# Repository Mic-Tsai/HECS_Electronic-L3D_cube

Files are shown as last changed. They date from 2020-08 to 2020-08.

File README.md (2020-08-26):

## L3D_cube_4x4x4



Use the microphone to design an interactive experience.
You will figure out the LEDs will start dancing with the music!

```
Arduino tool kit, and require following breakout board:
- MCU: Arduino 
- Display: WS2812B-5050
- Power source: Li-Po Battery
```

##

### **About Mic**

Director of HECS, design light painting product which contains hardware layout and software programming.

- [Resume](https://drive.google.com/file/d/1NEWwNo3X4ogJMNzp6jpFyT0a6GPGhs7Q/view)

## 

### **About HECS**

If you interesting how it works please refer for detail:

- [HECS Electronics](https://drive.google.com/file/d/1tgr780FQ_Ib0JO3FdQn_M6LVbDeVmUmG/view?usp=sharing)

## 

If you want to buy this board and are in Taiwan, please visit my shop: 

Will OPEN SOON:
* [HECS SHOP](https://www.)
* Contact me via mail (xbcke12345@gmail.com)
* If this project helping. Please generously support =)

   

##
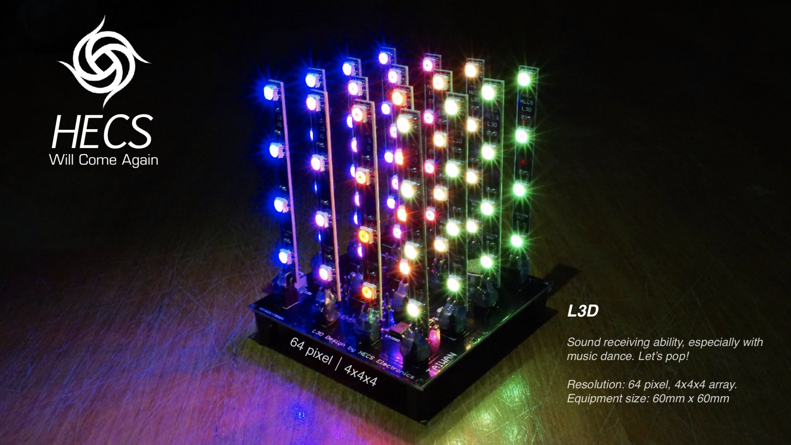
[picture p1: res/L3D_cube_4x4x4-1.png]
*L3D_cube_4x4x4*

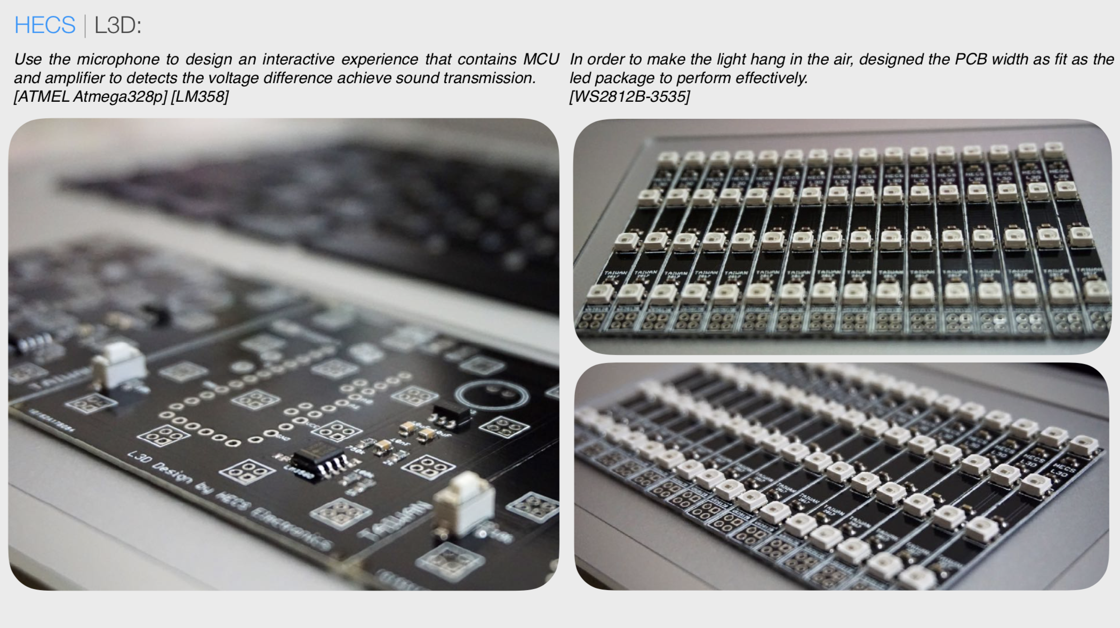
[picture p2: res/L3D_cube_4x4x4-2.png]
*L3D_cube_4x4x4*

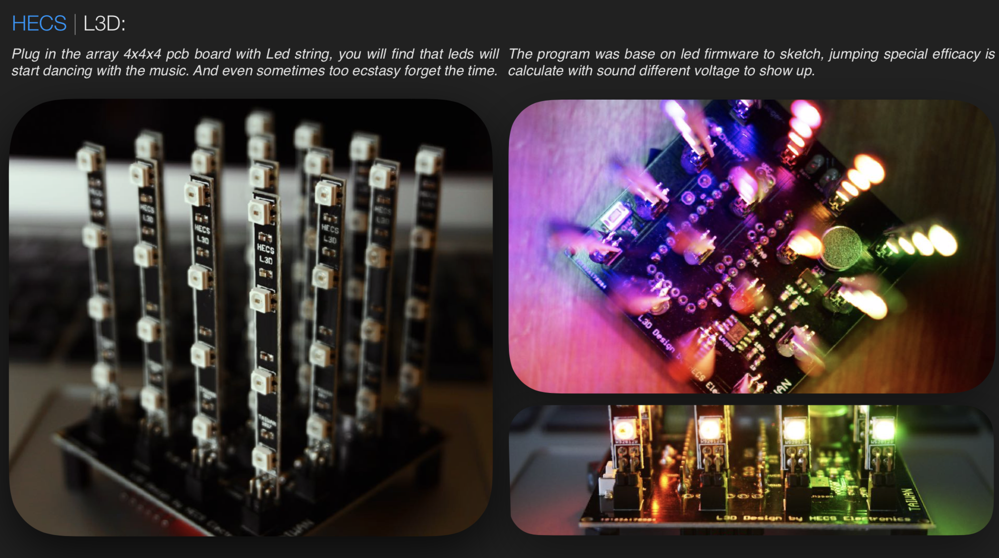
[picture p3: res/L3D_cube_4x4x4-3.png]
*L3D_cube_4x4x4*

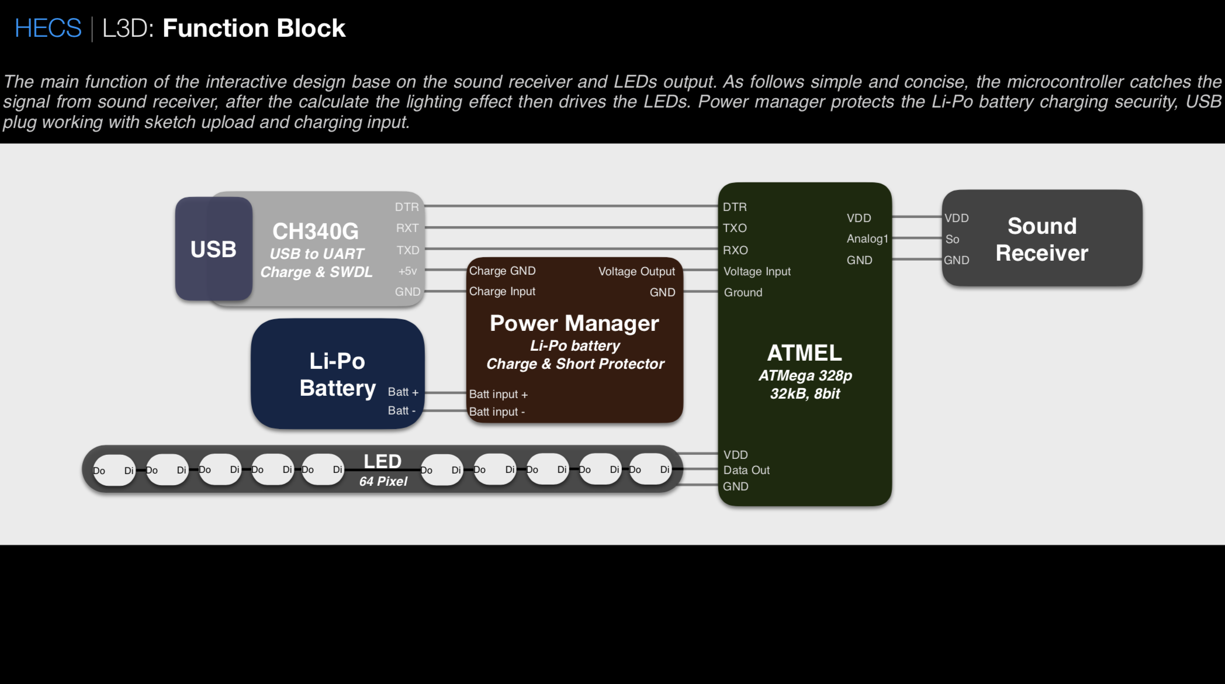
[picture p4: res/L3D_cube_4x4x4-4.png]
*L3D_cube_4x4x4*

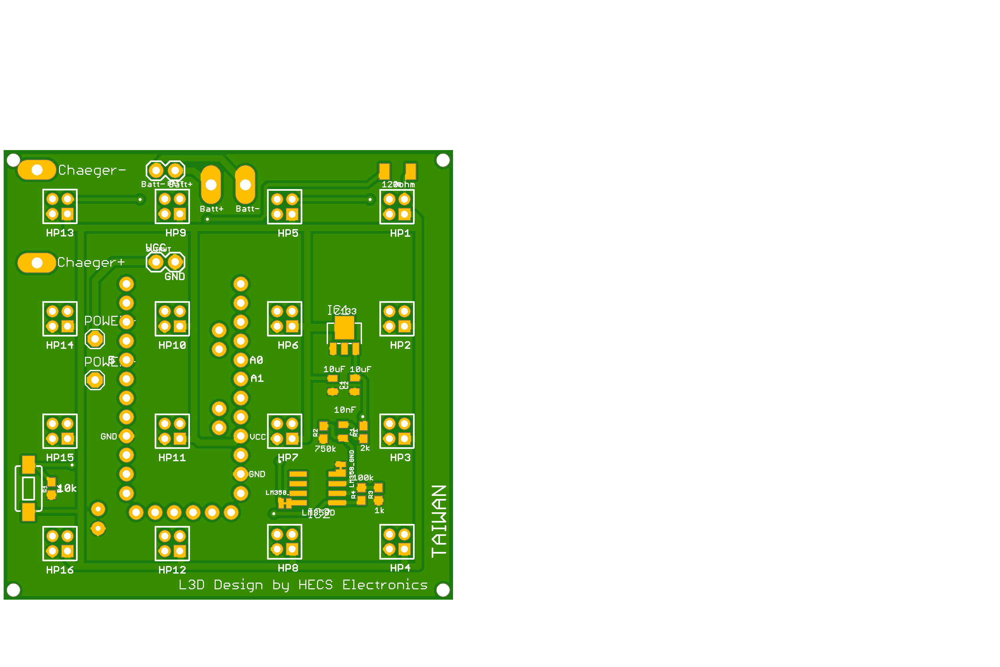
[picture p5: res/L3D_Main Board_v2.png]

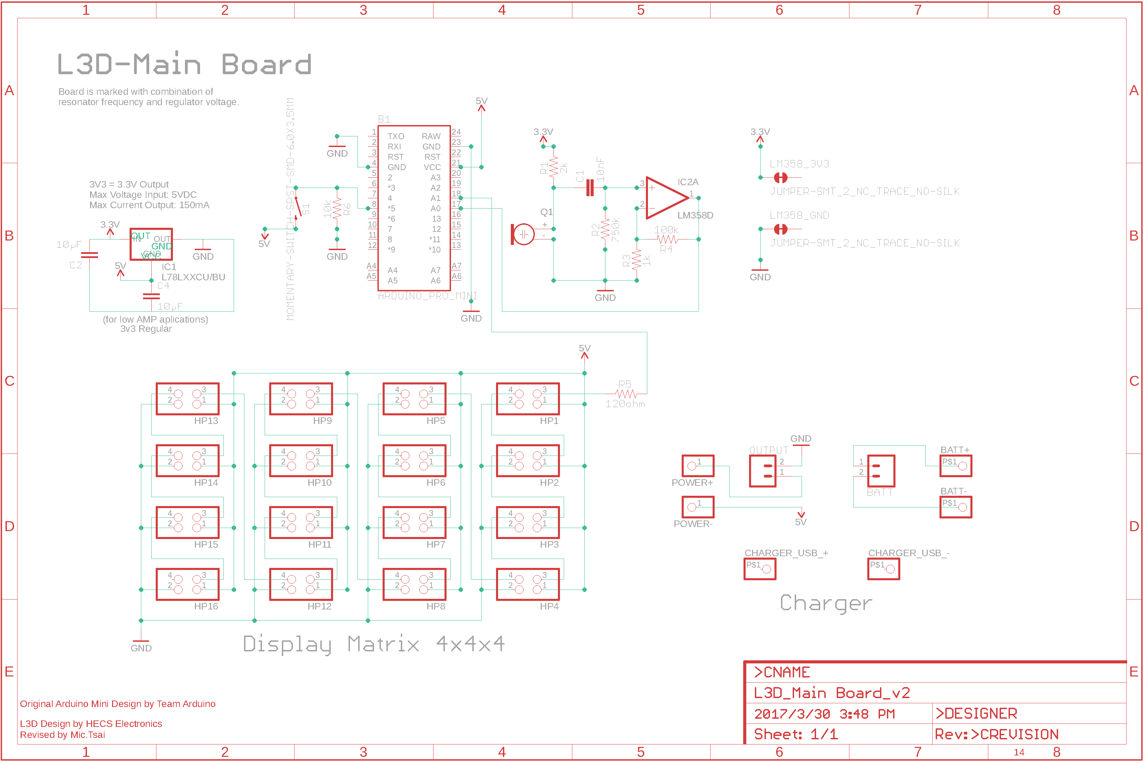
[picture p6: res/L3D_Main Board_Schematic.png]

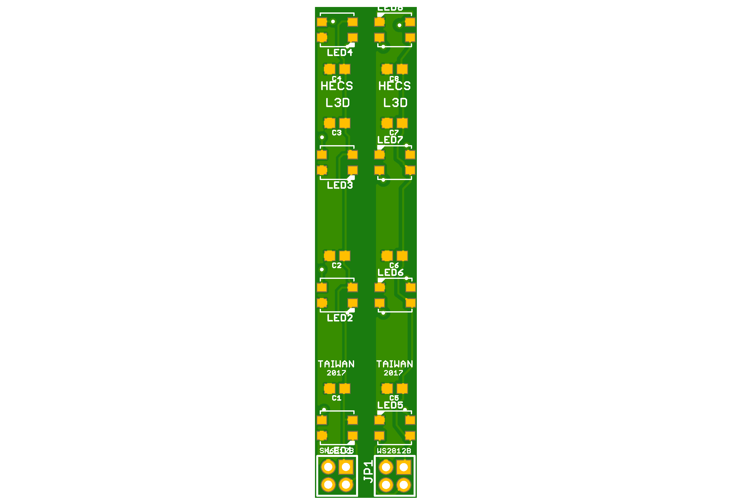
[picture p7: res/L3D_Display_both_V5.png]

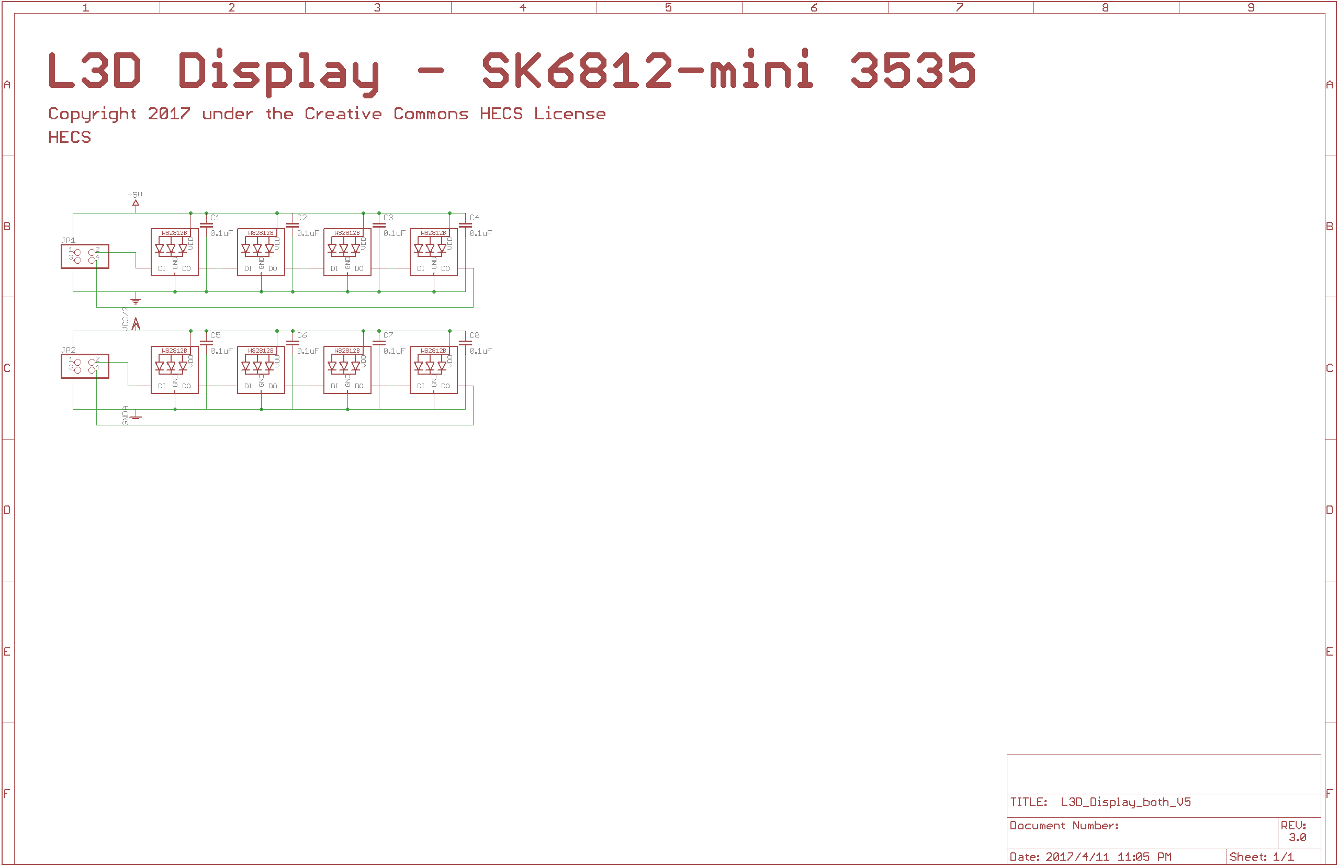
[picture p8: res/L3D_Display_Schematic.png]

## 

>### License Information
>>This product is open source! Both, our hardware and software are open source and licensed under the following:
>>#### Hardware
>>>All hardware is released under [Creative Commons Share-alike 4.0 International](http://creativecommons.org/licenses/by-sa/4.0/)
>>#### Software 
>>>All software is released under the MIT License [http://opensource.org/licenses/MIT](http://opensource.org/licenses/MIT)
>>#### Documentation
>>>The documentation on this page is released under [Creative Commons Share-alike 4.0 International](http://creativecommons.org/licenses/by-sa/4.0/)

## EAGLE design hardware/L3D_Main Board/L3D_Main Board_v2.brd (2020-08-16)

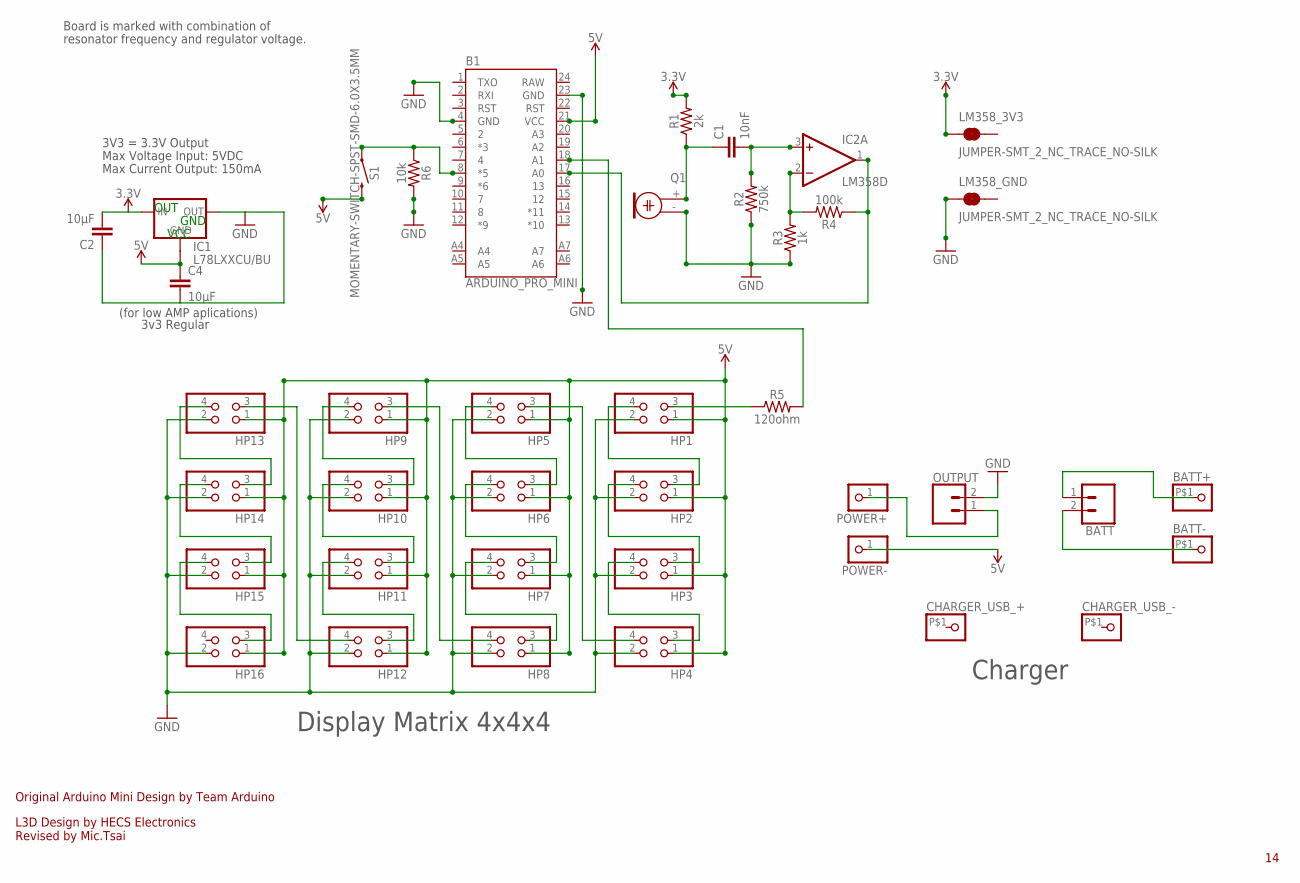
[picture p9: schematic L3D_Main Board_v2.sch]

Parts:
B1: ARDUINO_PRO_MINI
BATT: CONN_02; 1X02
BATT+: PINHD-1X1-BIGPOGO; 1X1-BIGPOGO
BATT-: PINHD-1X1-BIGPOGO; 1X1-BIGPOGO
C1: 10nF; 0805
C2, C4: 10µF; 0805
CHARGER_USB_+: PINHD-1X1-BIGPOGO; 1X1-BIGPOGO
CHARGER_USB_-: PINHD-1X1-BIGPOGO; 1X1-BIGPOGO
HP1, HP2, HP3, HP4, HP5, HP6, HP7, HP8, HP9, HP10, HP11, HP12, HP13, HP14, HP15, HP16: PINHD-2X2_2.00; 2X02M
IC1: L78LXXCU/BU; SOT89
IC2: LM358D; SO08
LM358_3V3, LM358_GND: JUMPER-SMT_2_NC_TRACE_NO-SILK; SMT-JUMPER_2_NC_TRACE_NO-SILK
OUTPUT: CONN_02; 1X02
POWER+: PINHD-1X1; 1X01
POWER-: PINHD-1X1; 1X01
Q1: ELECTRET; 9.7ELECTRET
R1: 2k; 0603
R2: 750k; 0603
R3: 1k; 0603
R4: 100k; 0603
R5: 120ohm; 1210
R6: 10k; 0603
S1: MOMENTARY-SWITCH-SPST-SMD-6.0X3.5MM; TACTILE_SWITCH_SMD_6.0X3.5MM

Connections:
3.3V: C2.2, IC1.3 (IN), LM358_3V3.1, R1.2
5V: B1.21 (VCC), C4.1, HP1.1, HP2.1, HP3.1, HP4.1, HP5.1, HP6.1, HP7.1, HP8.1, HP9.1, HP10.1, HP11.1, HP12.1, HP13.1, HP14.1, HP15.1, HP16.1, IC1.4 (GND1), POWER-.1, S1.2
GND: B1.4 (GND), B1.23 (GND), C2.1, C4.2, HP1.2, HP2.2, HP3.2, HP4.2, HP5.2, HP6.2, HP7.2, HP8.2, HP9.2, HP10.2, HP11.2, HP12.2, HP13.2, HP14.2, HP15.2, HP16.2, IC1.1 (OUT), LM358_GND.1, OUTPUT.2, Q1.- (1), R2.1, R3.1, R6.2
unnamed: C1.2, IC2.3 (+IN), R2.2
unnamed: C1.1, Q1.+ (2), R1.1
unnamed: IC2.2 (-IN), R3.2, R4.2
unnamed: HP1.4, HP2.3
unnamed: HP2.4, HP3.3
unnamed: HP3.4, HP4.3
unnamed: HP4.4, HP5.3
unnamed: HP5.4, HP6.3
unnamed: HP6.4, HP7.3
unnamed: HP7.4, HP8.3
unnamed: HP8.4, HP9.3
unnamed: HP9.4, HP10.3
unnamed: HP10.4, HP11.3
unnamed: HP11.4, HP12.3
unnamed: HP12.4, HP13.3
unnamed: HP13.4, HP14.3
unnamed: HP14.4, HP15.3
unnamed: HP15.4, HP16.3
unnamed: B1.17 (A0), IC2.1 (OUT), R4.1
unnamed: B1.8 (*5), R6.1, S1.1
unnamed: OUTPUT.1, POWER+.1
unnamed: B1.18 (A1), R5.2
unnamed: HP1.3, R5.1
unnamed: BATT.1, BATT+.P$1
unnamed: BATT.2, BATT-.P$1
RAW: B1.24 (RAW)
V+: IC2.8 (V+)
V-: IC2.4 (V-)

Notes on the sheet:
L3D Design by HECS Electronics Revised by Mic.Tsai
Original Arduino Mini Design by Team Arduino
Max Voltage Input: 5VDC
Max Current Output: 150mA
Board is marked with combination of
resonator frequency and regulator voltage.
3V3 = 3.3V Output
3v3 Regular
(for low AMP aplications)
OUT
GND
VCC
Display Matrix 4x4x4
Charger

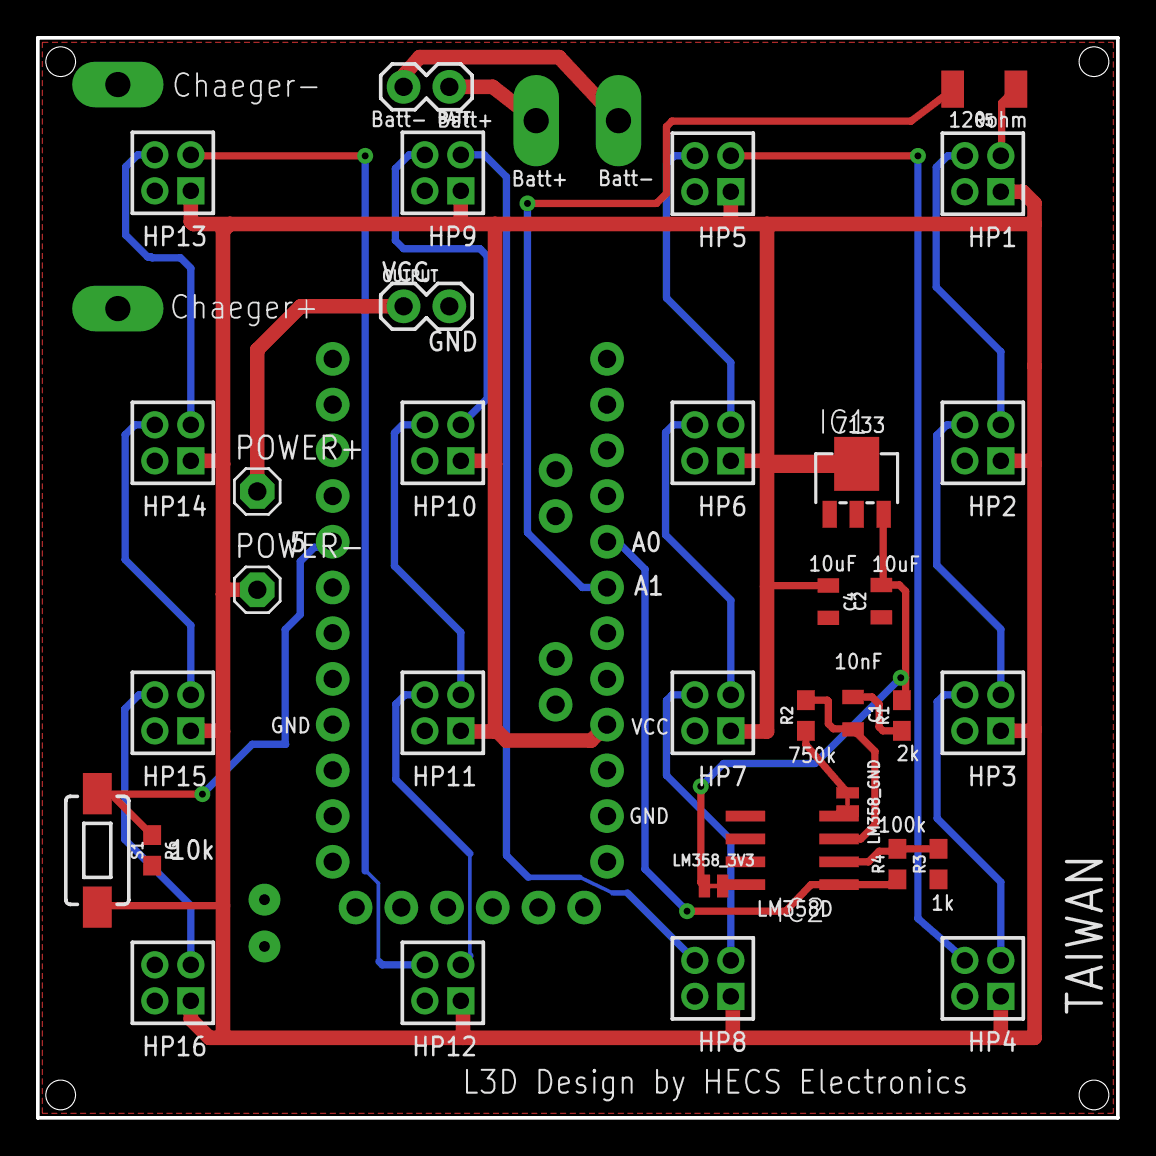
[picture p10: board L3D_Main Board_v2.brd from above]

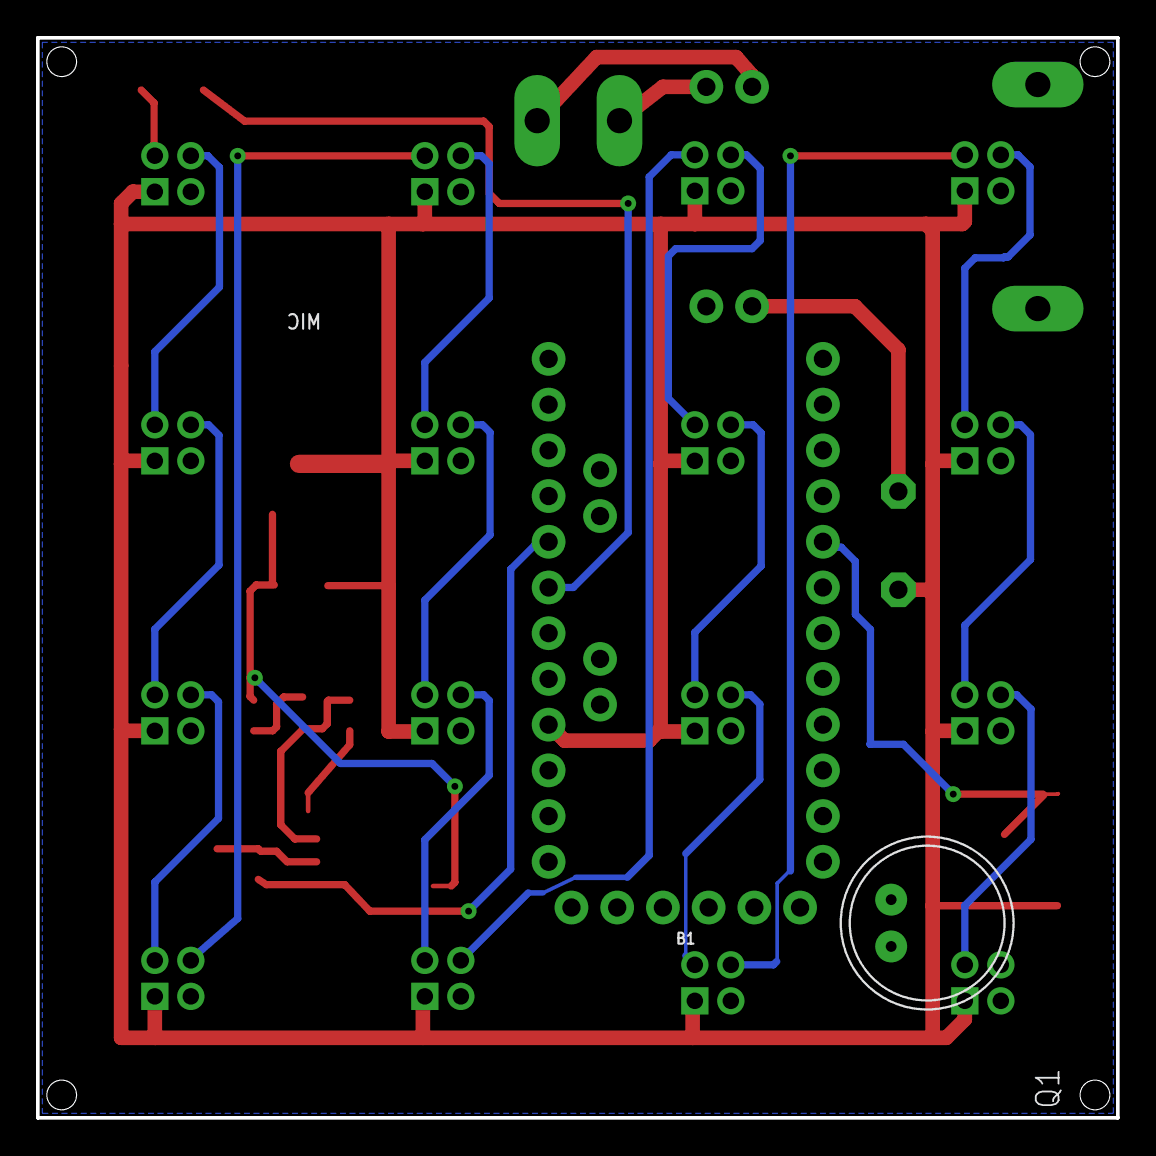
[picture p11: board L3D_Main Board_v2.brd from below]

Board: 2 copper layers, 60.0 x 60.0 mm, 40 parts (4 on the bottom side), 28 nets.

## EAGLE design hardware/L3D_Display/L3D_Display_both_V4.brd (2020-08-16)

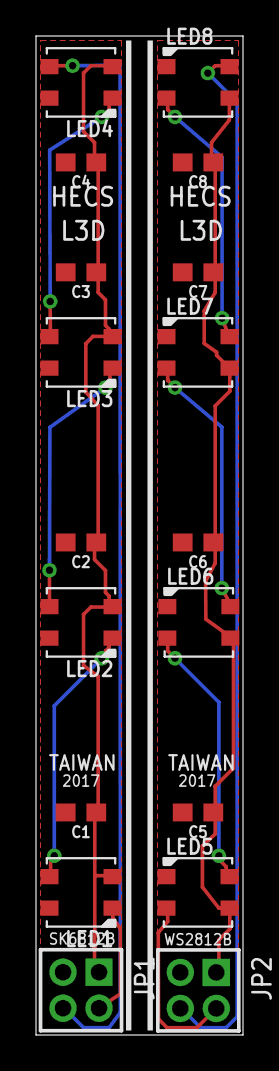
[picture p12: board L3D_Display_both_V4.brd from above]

Board: 2 copper layers, 11.5 x 55.5 mm, 18 parts (0 on the bottom side), 14 nets.

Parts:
C1, C2, C3, C4, C5, C6, C7, C8: 0.1uF; 0603
JP1, JP2: 2X02M
LED1, LED2, LED3, LED4, LED5, LED6, LED7, LED8: WS2812B3535; LED3535

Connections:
+5V: C1.1, C2.1, C3.1, C4.1, JP1.1, LED1.2, LED2.2, LED3.2, LED4.2
COM: C1.2, C2.2, C3.2, C4.2, JP1.3, LED1.4, LED2.4, LED3.4, LED4.4
GNDA: C5.2, C6.2, C7.2, C8.2, JP2.3, LED5.1, LED6.1, LED7.1, LED8.1
unnamed: JP1.4, LED4.3
unnamed: LED1.3, LED2.1
unnamed: LED2.3, LED3.1
unnamed: LED3.3, LED4.1
unnamed: LED5.4, LED6.2
unnamed: JP1.2, LED1.1
unnamed: LED6.4, LED7.2
unnamed: LED7.4, LED8.2
unnamed: JP2.2, LED5.2
unnamed: JP2.4, LED8.4
VCC/2: C5.1, C6.1, C7.1, C8.1, JP2.1, LED5.3, LED6.3, LED7.3, LED8.3

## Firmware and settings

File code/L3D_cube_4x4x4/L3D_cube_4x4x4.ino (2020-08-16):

// ###################################################################################
// # Project: L3D Cube 4x4x4
// # Engineer:  Mic.Tsai
// # Date:  8 July 2017
// # Objective: Dev.board
// # Usage: ATMEL328P
// ###################################################################################

#include <math.h>
#define N_PIXELS  64  // Number of pixels in strand
#define MIC_PIN   A0  // Microphone is attached to this analog pin
#define LED_PIN   A1  // NeoPixel LED strand is connected to this pin
#define SAMPLE_WINDOW   6  // Sample window for average level
#define PEAK_HANG 25 //Time of pause before peak dot falls
#define PEAK_FALL 1 //Rate of falling peak dot
#define INPUT_FLOOR 200 //Lower range of analogRead input
#define INPUT_CEILING 435 //Max range of analogRead input, the lower the value the more sensitive (1023 = max)
                          //800-->5V
                          //300-->3.3V

#include <Adafruit_NeoPixel.h>
#include "WS2812_Definitions.h"
#define PIN A1
#define LED_NUM 64
#define LED_COUNT 64

Adafruit_NeoPixel strip = Adafruit_NeoPixel(LED_NUM, PIN, NEO_GRB + NEO_KHZ800);
volatile int State;
int time = 6;


byte peak = 16;      // Peak level of column; used for falling dots
unsigned int sample;

byte dotCount = 0;  //Frame counter for peak dot
byte dotHangCount = 0; //Frame counter for holding peak dot

//Adafruit_NeoPixel strip = Adafruit_NeoPixel(N_PIXELS, LED_PIN, NEO_GRB + NEO_KHZ800);

//===============================================================
//===============================================================
//=================== Matrix Flow ===============================

int DelayTime = 10;
int Flow_ADR;

unsigned char FlowMatrix1[100]  = 
{
  5,10,15,20,25,50,75,100,125,124,123,122,121      ,
};

unsigned char FlowMatrix2[100]  = 
{
  5,30,55,80,105,104,103,102,101,106,111,116,121   ,
};

unsigned char FlowMatrix3[100]  = 
{
  5,4,3,2,1,6,11,16,21,46,71,96,121                ,
};


unsigned char FlowMatrix4[100]  = 
{
   5,10,15,20,25,24,23,22,21      ,
};

unsigned char FlowMatrix5[100]  = 
{
   5,30,55,80,105,110,115,120,125  ,
};

unsigned char FlowMatrix6[100]  = 
{
   5,4,3,2,1,26,51,76,101,106               ,
};

//=================== Matrix Flow ===============================
//===============================================================
//===============================================================

//===============================================================
//===============================================================
//=================== Snake beside Flow =========================

unsigned char FlowSnakeBeside[150]  = 
{
   1,2,3,4,5,10,15,20,25,50,75,100,125,124,123,122,121,116,111,106,101,76,51,26,1,6,11,16,21,22,23,24,25,20,15,10,5,30,55,80,105,104,103,102,101,106,
   111,116,121,96,71,46,21,22,23,24,25,20,15,10,5,4,3,2,1,26,51,76,101,106,111,116,121,122,123,124,125,100,75,50,25,20,15,10,5,30,55,80,105,104,103,
   102,101,76,51,26,1,
};
//=================== Snake beside Flow =========================
//===============================================================
//===============================================================

//===============================================================
//===============================================================
//=================== Snake Random Flow =========================

unsigned char FlowSnakeRandom[300]  = 
{
   1,6,7,8,9,10,35,40,45,44,43,42,41,66,91,116,111,106,101,102,103,104,79,54,29,4,9,14,19,44,69,94,119,114,109,108,83,58,33,38,43,48,73,98,123,118
   ,113,108,83,58,33,28,27,26,31,36,41,46,47,48,49,50,45,40,35,60,59,58,57,62,63,64,65,70,69,68,67,62,57,52,27,26,31,36,41,46,47,48,49,50,45,70,95
   ,90,85,84,83,82,81,86,87,88,89,90,65,64,63,62,61,56,51,26,31,32,37,42,47,48,49,50,45,40,35,30,5,5,13,17,21,46,96,91,86,81,76,101,106,111,116,121,
   122,123,118,113,108,103,102,101,76,51,26,1,6,11,16,21,22,23,24,25,20,15,10,5,4,3,2,1,26,31,36,41,46,47,48,49,50,45,40,35,30,29,28,27,26,51,56,61
   ,66,71,72,73,74,75,70,65,60,55,54,53,52,51,76,81,86,91,96,97,98,99,100,95,90,85,80,79,78,77,76,101,106,111,116,121,122,123,124,125,120,115,110
   ,105,104,103,102,101
};
//=================== Snake beside Flow =========================
//===============================================================
//===============================================================

int led = 13;
const byte SW = 5;
boolean LastState = LOW;
boolean toggle = LOW;
byte Click = 0;

int BootTime = 60;


void setup() {                
  strip.begin();
  strip.show(); // Initialize all pixels to 'off'
  pinMode(led, OUTPUT);
  pinMode(SW, INPUT);
  digitalWrite(SW, LOW);
  Click = 2;
}

//==========================================================================================
//========================================= S T A R T ======================================
//==========================================================================================

//==========================================================================================
//========================================= L O O P ======================================
//==========================================================================================

void loop() {
  
  boolean b1 = digitalRead(SW);
  
  if (b1 != LastState){
    delay(1);
    boolean b2 = digitalRead(SW);
    
    if (b1 == b2){
      LastState = b1;
      Click ++;    
    }
  }

  //==============================================================================================================

  if (Click == 2){                          //
      unsigned long startMillis= millis();  // Start of sample window
      float peakToPeak = 0;   // peak-to-peak level
    
      unsigned int signalMax = 0;
      unsigned int signalMin = 1023;
      unsigned int c, y;
    
    
      // collect data for length of sample window (in mS)
      while (millis() - startMillis < SAMPLE_WINDOW)
      {
        sample = analogRead(MIC_PIN);
        if (sample < 1024)  // toss out spurious readings
        {
          if (sample > signalMax)
          {
            signalMax = sample;  // save just the max levels
          }
          else if (sample < signalMin)
          {
            signalMin = sample;  // save just the min levels
          }
        }
      }
      peakToPeak = signalMax - signalMin;  // max - min = peak-peak amplitude
     
      // Serial.println(peakToPeak);
    
    
      //Fill the strip with rainbow gradient
      for (int i=0;i<=strip.numPixels()-1;i++){
        strip.setPixelColor(i,Wheel2(map(i,0,strip.numPixels()-1,30,150)));
      }
    
    
      //Scale the input logarithmically instead of linearly
      c = fscale(INPUT_FLOOR, INPUT_CEILING, strip.numPixels(), 0, peakToPeak, 2);
    
      
    
    
      if(c < peak) {
        peak = c;        // Keep dot on top
        dotHangCount = 0;    // make the dot hang before falling
      }
      if (c <= strip.numPixels()) { // Fill partial column with off pixels
        drawLine(strip.numPixels(), strip.numPixels()-c, strip.Color(0, 0, 0));
      }
    
      // Set the peak dot to match the rainbow gradient
      y = strip.numPixels() - peak;
      
      strip.setPixelColor(y-1,Wheel2(map(y,0,strip.numPixels()-1,30,150)));
    
      strip.show();
    
      // Frame based peak dot animation
      if(dotHangCount > PEAK_HANG) { //Peak pause length
        if(++dotCount >= PEAK_FALL) { //Fall rate 
          peak++;
          dotCount = 0;
        }
      } 
      else {
        dotHangCount++; 
      }
  }
  
  //==============================================================================================================
  
  if (Click == 4){                          //
    SnakeBesideFlow(1);
    JPflowC1(3);
    SnakeRandomFlow(1);
  }
  
  //==============================================================================================================
  
  if (Click == 6){                          //
    white();
    red();
    blue();
    green();
    purple();
    colorWipe(strip.Color(255, 0, 0), 2); // Red
    colorWipe(strip.Color(0, 255, 0), 5); // Green
    colorWipe(strip.Color(0, 0, 255), 5); // Blue
    theaterChase(strip.Color(127, 127, 127), 30); // White
    theaterChase(strip.Color(127,   0,   0), 30); // Red
    theaterChase(strip.Color(  0,   0, 127), 30); // Blue
  
    rainbowALL(8);
    rainbowCycle(5);
    theaterChaseRainbow(4);
    
    Click = 2;
  }
}

//==========================================================================================
//========================================= L O O P ========================================
//==========================================================================================

//==========================================================================================
//========================================= S T A R T ======================================
//==========================================================================================
  
  //colorWipe(strip.Color(255, 0, 0), 20); // Red
  //colorWipe(strip.Color(0, 255, 0), 50); // Green
  //colorWipe(strip.Color(0, 0, 255), 50); // Blue
 
  //theaterChase(strip.Color(127, 127, 127), 30); // White
  //theaterChase(strip.Color(127,   0,   0), 30); // Red
  //theaterChase(strip.Color(  0,   0, 127), 30); // Blue

  //rainbowALL(8);
  //rainbowCycle(5);
  //theaterChaseRainbow(40);

//==========================================================================================
//========================================= E F F E C T ====================================
//==========================================================================================

void JPfellWhite(uint8_t wait)
{
  for (int x=80; x<256; x++){
            colorWipe(strip.Color(x, x, x), 0);
            strip.show();
            delay(5);           
          }
}

//===============================================================
//===============================================================
//=================== Flow Loop =================================

void JPflowC1(int x)
{
   for (int i; i<x ;i++){
    MatrixFlow(1);
    //JPflow2(2);
    //JPSetWhite();
    delay(500);
   } 
}

void JPflowC2(int x)
{
   for (int i; i<x ;i++){
    MatrixFlow(1);
    MatrixFlow(1);
    //JPflow2(2);
    //JPSetWhite();
    delay(500);
   } 
}

void JPflowC3(int x)
{
   for (int i; i<x ;i++){
    MatrixFlow(1);
    MatrixFlow(1);
    MatrixFlow(1);
    //JPSetWhite();
    delay(500);
   } 
}

void JPflowC4(int x)
{
   for (int i; i<x ;i++){
    MatrixFlow(1);
    MatrixFlow(1);
    MatrixFlow(1);
    MatrixFlow(1);
    JPSetWhite();
    delay(500);
   } 
}

void JPflowC5(int x)
{
   for (int i; i<x ;i++){
    MatrixFlow(1);
    MatrixFlow(1);
    MatrixFlow(1);
    MatrixFlow(1);
    MatrixFlow(1);
    JPSetWhite();
    delay(500);
   } 
}

void JPflowC6(int x)
{
   for (int i; i<x ;i++){
    MatrixFlow(1);
    MatrixFlow(1);
    MatrixFlow(1);
    MatrixFlow(1);
    MatrixFlow(1);
    MatrixFlow(1);
    JPSetWhite();
    //JPflow2(2);
    delay(500);
   } 
}
//=================== Flow Loop== ===============================
//===============================================================
//===============================================================

//===============================================================
//===============================================================
//=================== Matrix Flow ===============================
void MatrixFlow(uint8_t wait)
{
  uint16_t i, j;
   
   for (uint16_t i=0; i<=strip.numPixels()-104; i++){  //
      for (int x=0; x<strip.numPixels(); x++){
        //colorWipe(strip.Color(50, 50, 50), 0);
        //colorWipefast2(strip.Color(50, 50, 50));
        //strip.setPixelColor(x , 1, 1, 1);
        strip.setPixelColor(x , 0, 0, 0);
      }
      //
      
      strip.setPixelColor(FlowMatrix1[i] -1, 100, 100, 100);
      strip.setPixelColor(FlowMatrix2[i] -1, 100, 100, 100);
      strip.setPixelColor(FlowMatrix3[i] -1, 100, 100, 100);
      strip.setPixelColor(FlowMatrix4[i] -1, 100, 100, 100);
      strip.setPixelColor(FlowMatrix5[i] -1, 100, 100, 100);
      strip.setPixelColor(FlowMatrix6[i] -1, 100, 100, 100);
      //
      strip.setPixelColor(FlowMatrix1[i-1] -1, 100, 100, 100);
      strip.setPixelColor(FlowMatrix2[i-1] -1, 100, 100, 100);
      strip.setPixelColor(FlowMatrix3[i-1] -1, 100, 100, 100);
      strip.setPixelColor(FlowMatrix4[i-1] -1, 100, 100, 100);
      strip.setPixelColor(FlowMatrix5[i-1] -1, 100, 100, 100);
      strip.setPixelColor(FlowMatrix6[i-1] -1, 100, 100, 100);
      //
      strip.setPixelColor(FlowMatrix1[i-2] -1, 100, 100, 100);
      strip.setPixelColor(FlowMatrix2[i-2] -1, 100, 100, 100);
      strip.setPixelColor(FlowMatrix3[i-2] -1, 100, 100, 100);
      strip.setPixelColor(FlowMatrix4[i-2] -1, 100, 100, 100);
      strip.setPixelColor(FlowMatrix5[i-2] -1, 100, 100, 100);
      strip.setPixelColor(FlowMatrix6[i-2] -1, 100, 100, 100);
      //
      strip.setPixelColor(FlowMatrix1[i-3] -1, 100, 100, 100);
      strip.setPixelColor(FlowMatrix2[i-3] -1, 100, 100, 100);
      strip.setPixelColor(FlowMatrix3[i-3] -1, 100, 100, 100);
      strip.setPixelColor(FlowMatrix4[i-3] -1, 100, 100, 100);
      strip.setPixelColor(FlowMatrix5[i-3] -1, 100, 100, 100);
      strip.setPixelColor(FlowMatrix6[i-3] -1, 100, 100, 100);
      //
      strip.setPixelColor(FlowMatrix1[i-4] -1, 100, 100, 100);
      strip.setPixelColor(FlowMatrix2[i-4] -1, 100, 100, 100);
      strip.setPixelColor(FlowMatrix3[i-4] -1, 100, 100, 100);
      strip.setPixelColor(FlowMatrix4[i-4] -1, 100, 100, 100);
      strip.setPixelColor(FlowMatrix5[i-4] -1, 100, 100, 100);
      strip.setPixelColor(FlowMatrix6[i-4] -1, 100, 100, 100);
      //
      strip.setPixelColor(FlowMatrix1[i-5] -1, 100, 100, 100);
      strip.setPixelColor(FlowMatrix2[i-5] -1, 100, 100, 100);
      strip.setPixelColor(FlowMatrix3[i-5] -1, 100, 100, 100);
      strip.setPixelColor(FlowMatrix4[i-5] -1, 100, 100, 100);
      strip.setPixelColor(FlowMatrix5[i-5] -1, 100, 100, 100);
      strip.setPixelColor(FlowMatrix6[i-5] -1, 100, 100, 100);
      //
      strip.setPixelColor(FlowMatrix1[i-6] -1, 100, 100, 100);
      strip.setPixelColor(FlowMatrix2[i-6] -1, 100, 100, 100);
      strip.setPixelColor(FlowMatrix3[i-6] -1, 100, 100, 100);
      strip.setPixelColor(FlowMatrix4[i-6] -1, 100, 100, 100);
      strip.setPixelColor(FlowMatrix5[i-6] -1, 100, 100, 100);
      strip.setPixelColor(FlowMatrix6[i-6] -1, 100, 100, 100);
      //
      strip.setPixelColor(FlowMatrix1[i-7] -1, 100, 100, 100);
      strip.setPixelColor(FlowMatrix2[i-7] -1, 100, 100, 100);
      strip.setPixelColor(FlowMatrix3[i-7] -1, 100, 100, 100);
      strip.setPixelColor(FlowMatrix4[i-7] -1, 100, 100, 100);
      strip.setPixelColor(FlowMatrix5[i-7] -1, 100, 100, 100);
      strip.setPixelColor(FlowMatrix6[i-7] -1, 100, 100, 100);
      //
      strip.setPixelColor(FlowMatrix1[i-8] -1, 100, 100, 100);
      strip.setPixelColor(FlowMatrix2[i-8] -1, 100, 100, 100);
      strip.setPixelColor(FlowMatrix3[i-8] -1, 100, 100, 100);
      strip.setPixelColor(FlowMatrix4[i-8] -1, 100, 100, 100);
      strip.setPixelColor(FlowMatrix5[i-8] -1, 100, 100, 100);
      strip.setPixelColor(FlowMatrix6[i-8] -1, 100, 100, 100);
      
      //strip.setPixelColor(FlowMatrix[i-6], 100, 100, 100);
      //strip.setPixelColor(FlowMatrix[i-5], 100, 100, 100);
      //strip.setPixelColor(FlowMatrix[i-4], 100, 100, 100);
      // strip.setPixelColor(FlowMatrix[i-3], 100, 100, 100);
      //strip.setPixelColor(FlowMatrix[i-2], 100, 100, 100);
      //strip.setPixelColor(FlowMatrix[i-1], 100, 100, 100);
      //strip.setPixelColor(FlowMatrix[i], 100, 100, 100);
      //strip.setPixelColor(FlowMatrix[i+1], 100, 100, 100);
      
      strip.show();
      delay(DelayTime);
   }
}
//=================== Matrix Flow ===============================
//===============================================================
//===============================================================

//===============================================================
//===============================================================
//=================== Snake beside Flow =========================
void SnakeBesideFlow(uint8_t wait)
{
  uint16_t i, j;
   
   for (uint16_t i=0; i<=strip.numPixels()-22; i++){  //
      for (int x=0; x<strip.numPixels(); x++){
        //colorWipe(strip.Color(50, 50, 50), 0);
        //colorWipefast2(strip.Color(50, 50, 50));
        //strip.setPixelColor(x , 1, 1, 1);
        strip.setPixelColor(x , 0, 0, 0);
      }
      //     
      strip.setPixelColor(FlowSnakeBeside[i] -1, 100, 100, 100);
     //
      strip.setPixelColor(FlowSnakeBeside[i-1] -1, 100, 100, 100);
      //
      strip.setPixelColor(FlowSnakeBeside[i-2] -1, 100, 100, 100);
      //
      strip.setPixelColor(FlowSnakeBeside[i-3] -1, 100, 100, 100);
      //
      strip.setPixelColor(FlowSnakeBeside[i-4] -1, 100, 100, 100);
      //
      strip.setPixelColor(FlowSnakeBeside[i-5] -1, 100, 100, 100);
      //
      strip.setPixelColor(FlowSnakeBeside[i-6] -1, 100, 100, 100);
      //
      strip.setPixelColor(FlowSnakeBeside[i-7] -1, 100, 100, 100);
      //
      strip.setPixelColor(FlowSnakeBeside[i-8] -1, 100, 100, 100);
          
      strip.show();
      delay(DelayTime);
   }
}
//=================== Snake beside Flow =========================
//===============================================================
//===============================================================

//===============================================================
//===============================================================
//=================== SnakeRandomFlow== =========================
void SnakeRandomFlow(uint8_t wait)
{
  uint16_t i, j;
   
   for (uint16_t i=0; i<=strip.numPixels()+200; i++){  //
      for (int x=0; x<strip.numPixels(); x++){
        //colorWipe(strip.Color(50, 50, 50), 0);
        //colorWipefast2(strip.Color(50, 50, 50));
        //strip.setPixelColor(x , 1, 1, 1);
        strip.setPixelColor(x , 0, 0, 0);
      }
      //     
      strip.setPixelColor(FlowSnakeRandom[i] -1, 100, 100, 100);
     //
      strip.setPixelColor(FlowSnakeRandom[i-1] -1, 100, 100, 100);
      //
      strip.setPixelColor(FlowSnakeRandom[i-2] -1, 100, 100, 100);
      //     
      strip.setPixelColor(FlowSnakeRandom[i-3] -1, 100, 100, 100);
     //
      strip.setPixelColor(FlowSnakeRandom[i-4] -1, 100, 100, 100);
      //
      strip.setPixelColor(FlowSnakeRandom[i-5] -1, 100, 100, 100);
      //     
      strip.setPixelColor(FlowSnakeRandom[i-6] -1, 100, 100, 100);
     //
      strip.setPixelColor(FlowSnakeRandom[i-7] -1, 100, 100, 100);
      //
      strip.setPixelColor(FlowSnakeRandom[i-8] -1, 100, 100, 100);
          
      strip.show();
      delay(DelayTime);
   }
}
//=================== SnakeRandomFlow ===========================
//===============================================================
//===============================================================

void JPSetWhite()
{
      clearLEDs();
      for (int i=0; i<strip.numPixels(); i++)
      {
         strip.setPixelColor(i, 10, 10, 10);
      } 
      strip.show();  
      delay(1000);   
}

//==========================================================================================
//======================================= E F F E C T ======================================
//==========================================================================================

// Fill the dots one after the other with a color
void colorWipe(uint32_t c, uint8_t wait) {
  for(uint16_t i=0; i<strip.numPixels(); i++) {
    
      strip.setPixelColor(i, c);
      strip.show();
      delay(wait);      
  }
}

// Fill the dots one after the other with a color2
void colorWipefast2(uint32_t c) {
  for(uint16_t i=0; i<strip.numPixels(); i++) {
      strip.setPixelColor(i, c);    
  }
}

void rainbowALL(uint8_t wait) {
  uint16_t i, j;

  for(j=0; j<256; j++) {
    for(i=0; i<strip.numPixels(); i++) {
      strip.setPixelColor(i, Wheel2((i+j) & 255));
    }
    strip.show();
    delay(wait);
  }
}

// Slightly different, this makes the rainbow equally distributed throughout
void rainbowCycle(uint8_t wait) {
  uint16_t i, j;

  for(j=0; j<256*5; j++) { // 5 cycles of all colors on wheel
    for(i=0; i< strip.numPixels(); i++) {
      strip.setPixelColor(i, Wheel2(((i * 256 / strip.numPixels()) + j) & 255));
    }
    strip.show();
    delay(wait);
  }
}

//Theatre-style crawling lights.
void theaterChase(uint32_t c, uint8_t wait) {
  for (int j=0; j<10; j++) {  //do 10 cycles of chasing
    for (int q=0; q < 3; q++) {
      for (int i=0; i < strip.numPixels(); i=i+3) {
        strip.setPixelColor(i+q, c);    //turn every third pixel on
      }
      strip.show();
      delay(wait);
      for (int i=0; i < strip.numPixels(); i=i+3) {
        strip.setPixelColor(i+q, 0);        //turn every third pixel off
      }
    }
  }
}

//Theatre-style crawling lights with rainbow effect
void theaterChaseRainbow(uint8_t wait) {
  for (int j=0; j < 256; j++) {     // cycle all 256 colors in the wheel
    for (int q=0; q < 3; q++) {
        for (int i=0; i < strip.numPixels(); i=i+3) {
          strip.setPixelColor(i+q, Wheel2( (i+j) % 255));    //turn every third pixel on
        }
        strip.show();    
        delay(wait);    
        for (int i=0; i < strip.numPixels(); i=i+3) {
          strip.setPixelColor(i+q, 0);        //turn every third pixel off
        }
    }
  }
}
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

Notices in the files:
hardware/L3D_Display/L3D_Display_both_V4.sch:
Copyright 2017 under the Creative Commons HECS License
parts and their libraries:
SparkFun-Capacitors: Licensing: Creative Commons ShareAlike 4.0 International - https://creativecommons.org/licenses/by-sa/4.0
